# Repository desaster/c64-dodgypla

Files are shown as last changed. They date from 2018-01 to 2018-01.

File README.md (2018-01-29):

PLA replacement for C64.

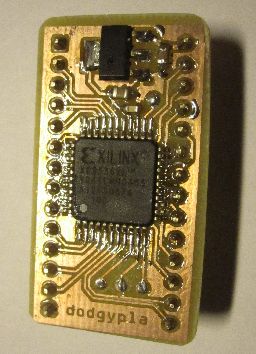
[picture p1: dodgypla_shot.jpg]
DodgyPLA picture


Based on the work by skoe:

[https://bitbucket.org/skoe/pla](1)
[http://skoe.de/docs/c64-dissected/pla/c64_pla_dissected_a4ds.pdf](2)

This design uses the Xilinx XC9536XL, which has 5V tolerant inputs essential
for operation with the Commodore 64.

As opposed to skoe's design, the required CASRAM delay is implemented in
Verilog instead of using additional components.

This project includes:

* A Xilinx ISE project written in Verilog for Xilinx XC9536XL
* A KiCad project including a board designed for home etching

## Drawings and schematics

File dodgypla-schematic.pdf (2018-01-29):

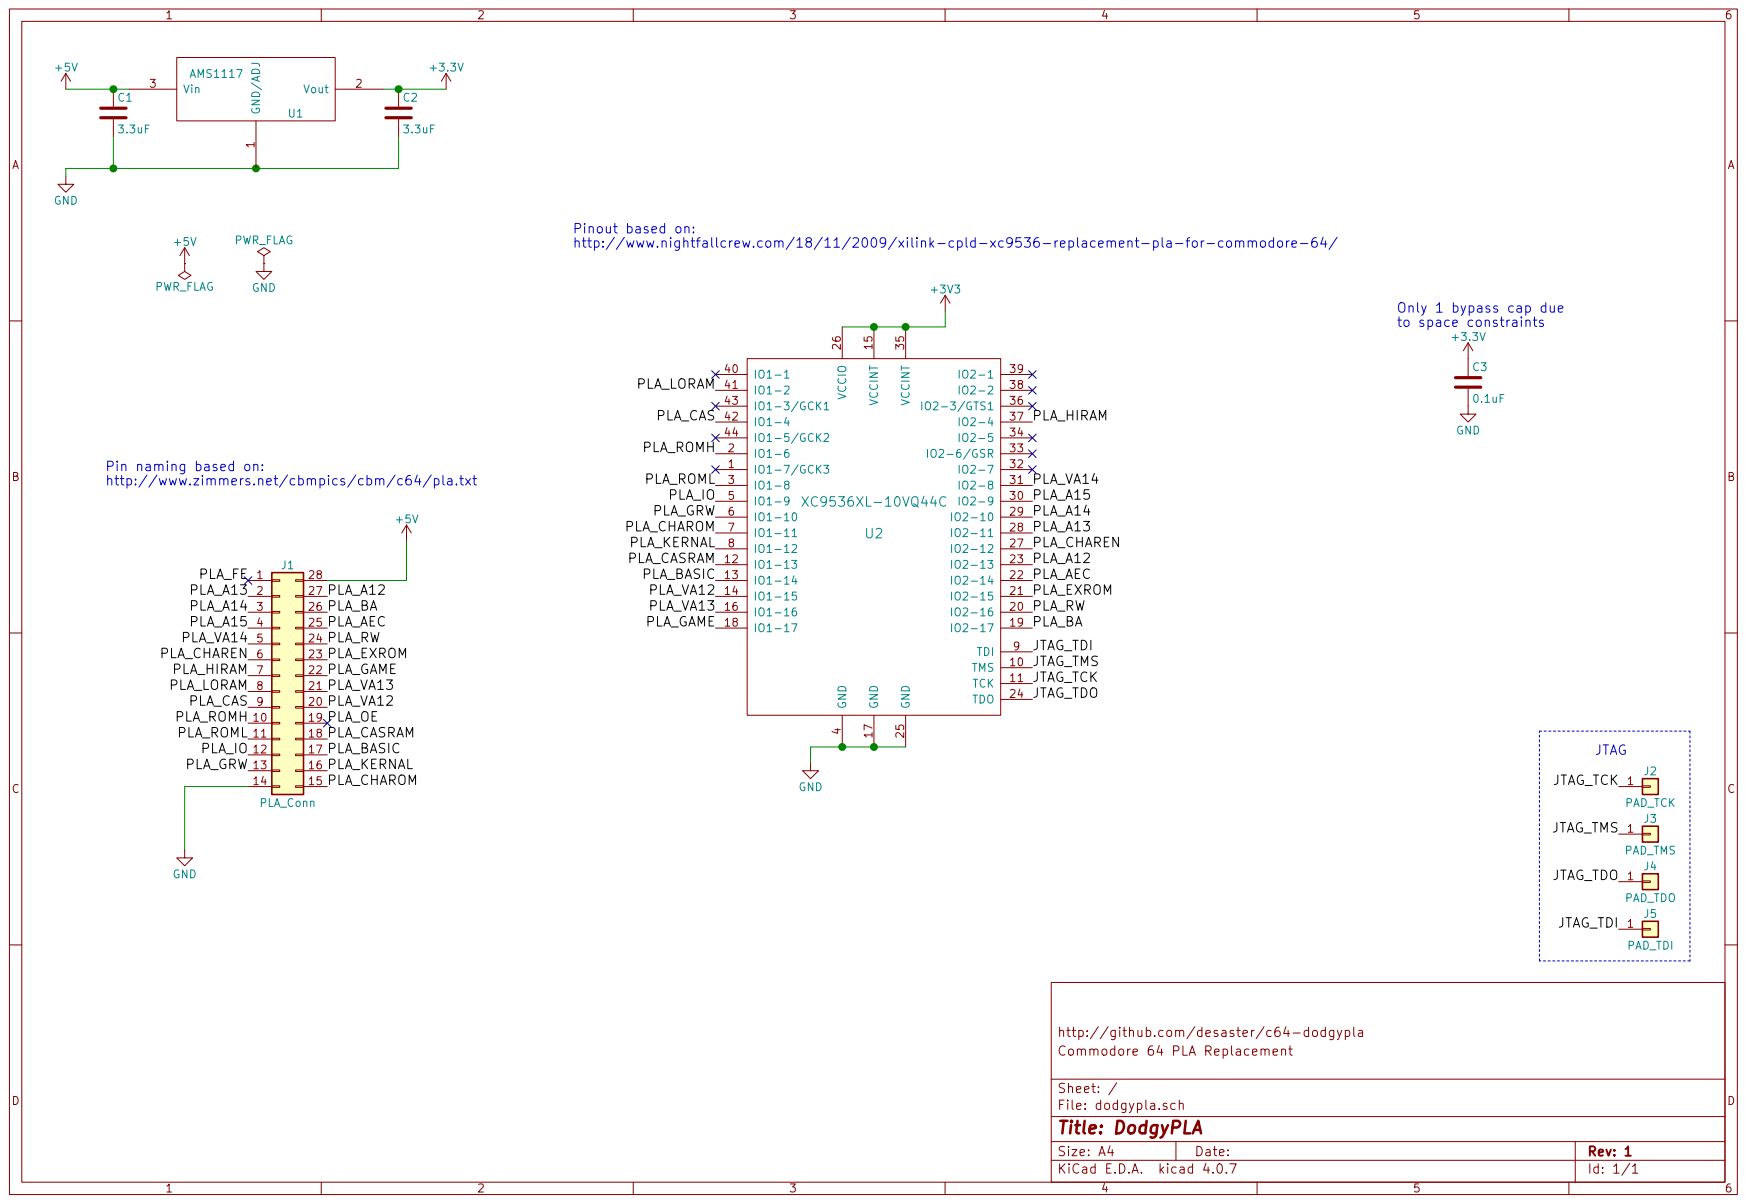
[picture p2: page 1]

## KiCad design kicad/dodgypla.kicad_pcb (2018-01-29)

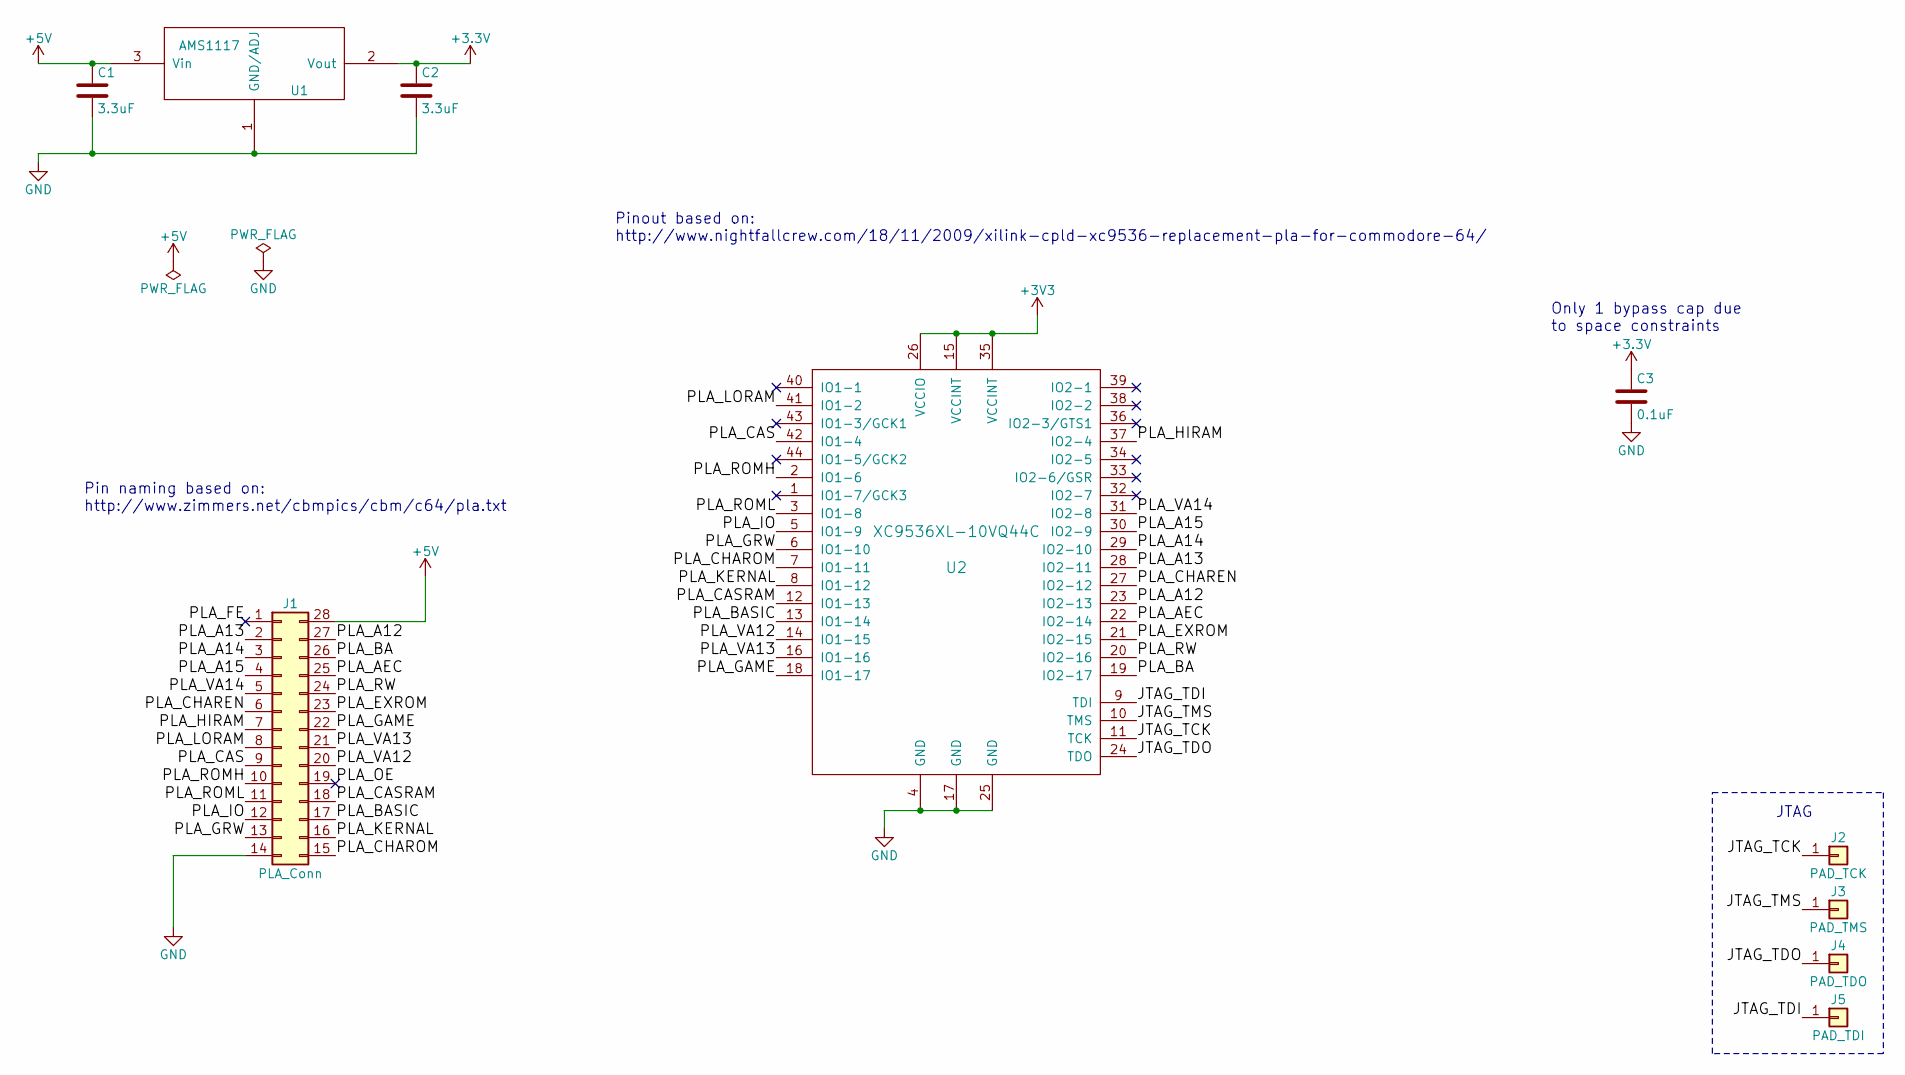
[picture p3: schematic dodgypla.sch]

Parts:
C1, C2: 3.3uF; C_0805
C3: 0.1uF; C_0603
J1: PLA_Conn; DIP-28_W15.24mm_Socket
J2: PAD_TCK; testpad_1.6mm
J3: PAD_TMS; testpad_1.6mm
J4: PAD_TDO; testpad_1.6mm
J5: PAD_TDI; testpad_1.6mm
U1: AMS1117; SOT-223-3Lead_TabPin2
U2: XC9536XL-10VQ44C; LQFP-44_10x10mm_Pitch0.8mm

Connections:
+5V: C1.1, J1.28, U1.3 (Vin)
/JTAG_TCK: J2.1, U2.11 (TCK)
/JTAG_TDI: J5.1, U2.9 (TDI)
/JTAG_TDO: J4.1, U2.24 (TDO)
/JTAG_TMS: J3.1, U2.10 (TMS)
/PLA_A12: J1.27, U2.23 (IO2-13)
/PLA_A13: J1.2, U2.28 (IO2-11)
/PLA_A14: J1.3, U2.29 (IO2-10)
/PLA_A15: J1.4, U2.30 (IO2-9)
/PLA_AEC: J1.25, U2.22 (IO2-14)
/PLA_BA: J1.26, U2.19 (IO2-17)
/PLA_BASIC: J1.17, U2.13 (IO1-14)
/PLA_CAS: J1.9, U2.42 (IO1-4)
/PLA_CASRAM: J1.18, U2.12 (IO1-13)
/PLA_CHAREN: J1.6, U2.27 (IO2-12)
/PLA_CHAROM: J1.15, U2.7 (IO1-11)
/PLA_EXROM: J1.23, U2.21 (IO2-15)
/PLA_FE: J1.1
/PLA_GAME: J1.22, U2.18 (IO1-17)
/PLA_GRW: J1.13, U2.6 (IO1-10)
/PLA_HIRAM: J1.7, U2.37 (IO2-4)
/PLA_IO: J1.12, U2.5 (IO1-9)
/PLA_KERNAL: J1.16, U2.8 (IO1-12)
/PLA_LORAM: J1.8, U2.41 (IO1-2)
/PLA_OE: J1.19
/PLA_ROMH: J1.10, U2.2 (IO1-6)
/PLA_ROML: J1.11, U2.3 (IO1-8)
/PLA_RW: J1.24, U2.20 (IO2-16)
/PLA_VA12: J1.20, U2.14 (IO1-15)
/PLA_VA13: J1.21, U2.16 (IO1-16)
/PLA_VA14: J1.5, U2.31 (IO2-8)
GND: C1.2, C2.2, C3.2, J1.14, U1.1 (GND/ADJ), U2.4 (GND), U2.17 (GND), U2.25 (GND)

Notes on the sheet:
JTAG
Pin naming based on: http://www.zimmers.net/cbmpics/cbm/c64/pla.txt
Pinout based on: http://www.nightfallcrew.com/18/11/2009/xilink-cpld-xc9536-replacement-pla-for-commodore-64/
Only 1 bypass cap due to space constraints

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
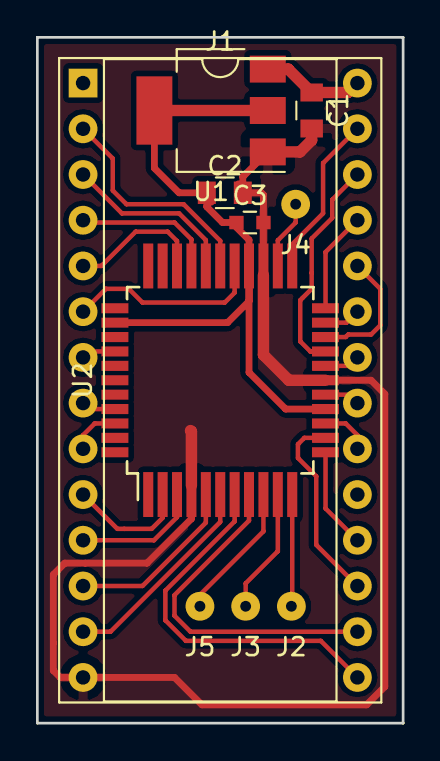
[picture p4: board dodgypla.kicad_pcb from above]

Board: 2 copper layers, 20.3 x 38.1 mm, 10 parts (0 on the bottom side), 31 nets.

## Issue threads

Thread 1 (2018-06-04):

PLA

patzik, 2018-06-04:
Not really an issue, but could you add the xsvf file to the repo? Makes programming a bit easier for me.

desaster, 2018-06-04:
I haven't actually used .xsvf myself, since I'm using a bit hacky way of programming the device with .svf and busblaster.

With a bit of confused clicking around in ISE iMPACT (I don't use xilinx tools very often), I managed to create an .xsvf file. I've attached it here for your convenience. I have no idea if it works, though.

[dodgypla_xsvf.zip](https://github.com/desaster/c64-dodgypla/files/2069343/dodgypla_xsvf.zip)

As for including it in in the repo, I'll give it some consideration. I'm usually against including compiled output among the source code, but maybe it could be shared as a release.

patzik, 2018-06-04:
I am trying to program it with an ever hackier way :-) I programmed a stm32 ‘bluepill’ board, to program the xc9536xl chip. Never tried it before and am having some problems. Don’t know where the problem lies, too many ‘new’ things in this process.
We’ll see how I get along. Could be a 2euro sollution to program it :-)

Verstuurd vanaf mijn iPhone

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

desaster, 2018-06-04:
Here are my notes about working with xilinx. The last parts might be interesting to you, since you're also doing a hacky way.

# Creating new project

Name: asdasd
Location: /home/desaster/projects/fpga/xilinx/asdasd
Working Directory /home/desaster/projects/fpga/xilinx/asdasd
(a folder will be created under this directory)

Device: XC9536XL
Package: VQ44
Speed: (check the chip?)

# Creating top level entity

Right click asdasd -> New Source
Verilog Module
File Name: asdasd

Add code, for example:

    `timescale 1ns / 1ps

    module ledblink(clk, LED);

    input clk;
    output LED;

    reg [32:0] cnt;
    always @(posedge clk) cnt <= cnt + 1;
    assign LED = cnt[23];

Right click asdasd.v -> Set as top module

If code and everything is ok, "Implement Design" appears in design tab.
Can run Synthetize now for test.

# Pin Assignment

Right click asdasd -> New Source -> Implementation Constraints File
File Name: pins

Add pin assignments, for example:

    NET "clk" LOC = "P1";
    NET "LED" LOC = "P32";

After this, the following steps should work:

- Synthesize
- Translate
- Fit
- Generate Programming File

# Generating SVF for programming

Design -> Configure Target Device

This starts iMPACT

File -> new

This pops up Welcome to iMPACT, where you can select:
Prepare Boundary-Scan File (SVF)

Choose an .svf file where all operations will be saved
Then select the previously generated .jed file

Double click Boundary Scan

Right click on the device -> Program
(if the programming properties are ok, then this should also erase and verify)

Output -> SVF File -> Stop writing to output

# Programming the SVF file using Bus Blaster

Before programming the the file, the SVF file needs to have it's freqency
changed.  Find the line with FREQUENCY and change 1E6 to 3E5

sudo /usr/local/bin/jtag

cable jtagkey vid=0x403 pid=0x6010 interface=0

If this fails, urjtag is built using libftd2xx and you need to run:

sudo rmmod ftdi_sio

When the cable command is ok, run:

detect

This should provide no errors:

jtag> detect
IR length: 8
Chain length: 1
Device Id: 01011001011000000010000010010011 (0x59602093)
  Manufacturer: Xilinx (0x093)
  Part(0):      xc9536xl (0x9602)
  Stepping:     5
  Filename:     /usr/local/share/urjtag/xilinx/xc9536xl/xc9536xl_vq44

If there is an error:

Unknown stepping! (0101) (/usr/local/share/urjtag/xilinx/xc9536xl/STEPPINGS)

Then you need to add the device to the STEPPINGS file:

0101    xc9536xl_vq44   5

If detect went okay, then you can program the file:

svf ~/projects/fpga/xilinx/asdasd/asdasd.svf stop progress

(Don't forget to add the stop and progress parameters)

Successful programming outputs:

detail: Parsing   5160/5163 ( 99%)detail:
detail: Scanned device output matched expected TDO values.

patzik, 2018-06-04:
I realized I have an altera usb blaster lying here, and I might be able to use it with urjtag to program an sfv file.
Can I ask you for the sfv file ;-)

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

patzik, 2018-06-04:
I am getting close, I got the usbblaster to recognize the xc9536xl with
urjtag, now I only need the svf file to program it. I know I should be able
to make it myself from the source, but I don't have ISE at the moment due
to a HD crash. And downloading/installing it just for this is more work
than just asking you nicely..  :-)

2018-06-04 21:44 GMT+02:00 Patrick Kerkhof <patzik@gmail.com>:

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

patzik, 2018-06-04:
I did install Xilinx ISE and generate a svf myself.
I assume I did it correct but I can’t seem to be able to program it.

I keep getting this error:

Warning: USB-Blaster frequency is fixed to 12000000 Hz  Error svf: mismatch at position 17 for TDO   in input file between line 41 col 1 and line 41 col 49  Error occurred for SVF command SDR.  Parsing   8500/8506 ( 99%)  Mismatches occurred between scanned device output and expected TDO values.

I’m lost at this point, any suggestions?

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

desaster, 2018-06-05:
Hmm no idea really, all I can guess is that the frequency is too high, since I also had to change that manually.

I believe I didn't have to use external pull-ups for the pins, but that might be worth a shot.

patzik, 2018-06-08:
There might be a problem with the svf file I generated, could you mail me the svf file you used so I can see if it is different?
I can id the chip via the jtag, so it is working….

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

desaster, 2018-06-10:
Attached is the svf file. There's nothing special about it though, except for the changed frequency.

[dodgypla_svf.zip](https://github.com/desaster/c64-dodgypla/files/2087602/dodgypla_svf.zip)

patzik, 2018-06-14:
Well, the svf I generated is exactly the same, so that wasn't the issue.
Out comes programming option number 3...
It just happens I was building an easyflash3 cartridge this week, and realized it also has a Xilinx chip on it which I had to program. This cartridge has an "onboard solution' for this.
So I thought why not use the jtag pins from this cartridge and program the pla this way.
It's a bit of a hack, but hey it's free!
Worked like a charm :-)
Thanks for your help, I'll upload a picture soon.

patzik, 2018-06-16:
Here's the picture ;-)

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

mamejay, 2018-07-07:
Hello patzik.  I have an easy flash 3 cart the same as yours.  I want to do the same hack as yourself.
Do I still use the same process as programming the EF3 using the following command?  Also do I still need to connect the cart to the C64 as well as the USB of the PC?
easp -p 0x8738 -v <svf_file>

patzik, 2018-07-07:
Yes the procedure is exactly the same as flashing the onboard chip. So with cart connected to the c64, and c64 has to be on. I use a different board design so make sure you check the connections.

mamejay, 2018-07-07:
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
Just to confirm this is the EF3 pinout.  Also are the programming pins the middle row?  Its hard to tell due to reflection that is in your picture.

patzik, 2018-07-07:
It’s the 4 pins of the middle row, and the gnd+vcc from the top row

mamejay, 2018-07-07:
Got it all working last night.  Hooked up my chip adapter to a breadboard so I could program them out of circuit and it all worked.   Thanks so much for your help.  Now just waiting on some caps to finish the build.

Closed 2018-08-05.

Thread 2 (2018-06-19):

Programmer to use and substitute 3.3uf caps

mamejay, 2018-06-19:
Hello there.  I know  this is probably a silly question.  This is my first time working with Xilinx chips.
I have experience with Arduino etc.
I am looking to get a generic JTAG cable which is stated to be compatible with the Xilinx ISE.
https://www.ebay.com.au/itm/262136736614

Lastly can I substitute the 3.3uf caps with another value?  I am just finding that they are not too common in Australia.
Thanks

desaster, 2018-06-19:
Personally, I don't have a proper jtag cable for xilinx, and I'm using bus blaster instead. The programmer you linked would be a better choice, but I have no experience with it so I can't tell if it works.

You can certainly substitute the caps for something else. I don't remember why I have 3.3uF caps there, since I'm probably using something else myself. They're probably from some reference design.

Looking at reference designs for voltage regulators, there's a wide range of different values used. I might just go with anything between 1uF and 10uF. To pick "proper" values, you'd have to ask someone else :)

mamejay, 2018-06-19:
Thank so much for that.  I have a heap of LM1117's so will use one of these with 1uf caps.  Hopefully I manage to perform the programming once I get the programmer

mamejay, 2018-07-09:
Finally got some built.  All working perfectly.  Thank you for your help

Closed 2018-08-05.

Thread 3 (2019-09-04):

AMS voltage

drakonia667, 2019-09-04:
Hi mate, is AMS1117 3.3V or 5V?

1c3d1v3r, 2019-09-04:
The CPLD is a 3.3V parts so I would guess 3.3V. You can also use a 3.6V regulator. 3.6V is still in spec and better for the signal levels.

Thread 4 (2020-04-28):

Severe audio glitches with Nano SwinSID in some boards?

modeler, 2020-04-28:
I have a 250407 Rev. B board with DodgyPLA (actually the hackup.net variant XCPLA) and Nano SwinSID. This combination of PLA and SID works fine in other boards, but in one board I get very crackly and distorted audio.

If I replace either of these, e.g. swap the SwinSID for ARMSID or swap the XCPLA for PLAnkton, the problem goes away. It is only this combination and only this particular board. I have other 250407 boards that are not affected. Has anyone else had this problem at all? I am not looking for a fix, but it would be nice to have some idea of why PLAnkton doesn't suffer from this.

1c3d1v3r, 2020-04-28:
I fixed this issue in my fork neatPLA. It's an easy fix. Add delay to all output ports. I implemented it by just inverting the signals twice. CASRAM delay could be expanded at the same time. 30ns works perfect. DodgyPLA got now 20ns which is too short for some oldest motherboards.

desaster, 2020-04-28:
Great that you've found a fix. The ~20ns CASRAM delay is directly based on a range in skoe's document, and I chose the average of that for most compatibility. I guess in real life it might not always be the best delay.

Adding delay to all output ports is curious. Were both CASRAM delay + all pins delay necessary for this fix?

I wonder if settings pins to slow slew rate would help with this - IIRC for now I've only enable it on CASRAM.

PS. I should probably add links to XCPLA & neatPLA in README, and keep my project as a sort of a reference design.

1c3d1v3r, 2020-04-28:
IIRC PLAnkton got even 40ns CASRAM delay.

CASRAM delay was increased to 30ns for old MB compatibility.
Delay to all other pins fixed the SwinSID issue. 30ns CASRAM was already implemented when testing this.

Just by using dodgypla_core.v from neatPLA should fix all issues since the delays are in that code.

modeler, 2020-04-28:
Thank you both! hackup.net provided an SVF file for use with OpenOCD, which is what I used to program my XCPLAs (using a Raspberry Pi as a JTAG programmer). I will see if I can generate an updated SVF using the project files from neatPLA.

Unable to test immediately but will close the issue as this looks pretty conclusive to me.

modeler, 2020-04-28:
I was able to take dodgypla_core.v from neatPLA as suggested and generate a new JED file with Xilinx ISE, then made an updated SVF with the delays implemented. This does indeed fix the problem with SwinSID in my board, thank you.

Made a fork of hackup.net's repo with these files in place of the originals, should anyone need them: https://github.com/modeler/c64-dodgypla

Closed 2020-04-28.

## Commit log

2018-01-29 add kicad design
    [dodgypla.kicad_pcb, dodgypla.sch]
2018-01-29 Add schematic in PDF format
